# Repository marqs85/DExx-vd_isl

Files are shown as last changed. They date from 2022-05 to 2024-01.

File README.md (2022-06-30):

DExx-vd_isl
==============

DExx-vd_isl is advanced video digitizer add-on module for a number of Terasic FPGA development boards. It has been initially used as a development board for OSSC Pro scan converter but over time has been tailored towards a standalone product. Please check the [wikipage](https://junkerhq.net/xrgb/index.php?title=DExx-vd_isl) for more information on usage and latest features.

[PCB](pcb/) and firmware of the project are open-source except for certain Intel VIP modules which are planned to be replaced by custom implementations over time. For most parts RTL and SW are derived from OSSC Pro [project](https://github.com/marqs85/ossc_pro/) with only small amount of adaptation code for the supported development boards.

Supported Terasic boards and board specific notes
----------------------------------------------------
* [DE10-Nano](board/de10-nano)
* [C5G](board/c5g)
* [DE2-115](board/de2-115)

Requirements for building and debugging firmware
---------------------------------------------------
* Hardware
  * DExx-vd_isl module and compatible development board

* Software
  * [Altera Quartus Prime + device support files for target FPGA family](http://dl.altera.com/?edition=lite) (v 21.1 or higher - free Lite Edition suffices)
  * Make

Building RTL (bitstream)
--------------------------
1. Load the project (board/\<board\>/\<boardname\>.qpf) in Quartus
2. Generate QSYS output files (only needed before first compilation or when QSYS structure has been modified)
    * Open Platform Designer (Tools -> Platform Designer)
    * Load platform configuration (sys.qsys)
    * Generate output (Generate -> Generate HDL, Generate)
    * Close Platform Designer
3. Build software image if not yet done so that it becomes part of the bitstream (see next section)
4. Generate the FPGA bitstream (Processing -> Start Compilation)
5. Ensure that there are no major timing violations by looking into Timing Analyzer report

NOTE: If the software image (software/sys_controller/mem_init/sys_onchip_memory2_0.hex) was not up to date at the time of compilation, bitstream can be quickly rebuilt with updated hex by running "Processing->Update Memory Initialization File" and "Processing->Start->Start Assembler" in Quartus.

NOTE2: Without Intel VIP license it's only possible to generate a time limited bitstream which needs connection to USB Blaster during use. VIP modules can be excluded by commenting out the "VIP" define from both top-level RTL and sysconfig.h in which case scaler mode is disabled.

Building software image
--------------------------
1. Generate software BSP (first-time only)
~~~~
cd board/<board>/software/sys_controller_bsp
nios2-bsp-generate-files --settings=settings.bsp --bsp-dir=.
~~~~
2. Enter software root directory:
~~~~
cd board/<board>/software/sys_controller
~~~~
3. Build SW for target configuration:
~~~~
make [OPTIONS] [TARGET]
~~~~
OPTIONS may include following definitions:
* APP_CFLAGS_DEFINED_SYMBOLS="-DDEBUG" (debug message are printed to stdout connected to JTAG UART, shown via nios2-terminal)

TARGET is typically one of the following:
* all (Default target. Compiles an ELF file)
* mem_init_generate (Generates a memory initialization file required for bitstream)
* clean (cleans ELF and intermediate files. Should be invoked every time OPTIONS are changed between compilations)

4. Optionally test updated SW by directly downloading memory image to block RAM via JTAG (with DE10-Nano TCK needs to be reduced, see board specific notes)
~~~~
nios2-download sys_controller.elf --go
~~~~

Bitstream deployment
----------------------
Depending on target platform, bitstream can be either stored into serial flash chip or SD card where it is automatically loaded every time FPGA is subsequently powered on.

To program flash on compatible boards, FPGA configuration file must be first converted into JTAG indirect Configuration file (.jic). Open conversion tool ("File->Convert Programming Files") in Quartus, click "Open Conversion Setup Data", select "ossc.cof" and press Generate. Then open Programmer, add generated file (output_files/<filename>.jic) and press Start after which flash is programmed. Installed/updated firmware is activated after power-cycling the board.

See board specific notes for building a SD card image containing the bitstream.

Debugging
------------
1. Rebuild the software in debug mode:
~~~~
make clean && make APP_CFLAGS_DEBUG_LEVEL="-DDEBUG" mem_init_generate
~~~~
2. Download memory image via JTAG and open terminal for UART
~~~~
nios2-download sys_controller.elf --go && nios2-terminal
~~~~
Remember to close nios2-terminal after debug session, otherwise any JTAG transactions will hang/fail.

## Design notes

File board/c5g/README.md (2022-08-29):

DExx-vd_isl on C5G
===========================

Hardware notes
-----------------
* C5G has series resistors between GPIO and FPGA (close solder jumper JP1)
* Digital audio needs to be connected directly to respective ADV7513 "test" pads

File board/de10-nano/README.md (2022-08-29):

DExx-vd_isl on DE10-Nano
===========================

Hardware notes
-----------------
* DE10-Nano has no series resistors between GPIO and FPGA (make sure JP1 is open)
* Uses GPIO0 block by default and Arduino header (D[7:4]) closest to FPGA
  * GPIO1 can be used with FW from de10n_gpio1 branch (useful for people using a Mister RAM expansion on GPIO0)
* Uses Nios2 soft-CPU to be in line with other board adaptations
  * TODO: evaluate if hard ARM core could be utilized with minimal configuration/code changes
* DE10-Nano user LEDs are too tightly packed and all same color so they are not much of use
* SPDIF input of ADV7513 is not connected (board can be modified to support SPDIF, see below)
* Due to booting from HPS, EPCQ flash is not accessible. Settings are stored on SD card

SPDIF mod
------------
In order to enable SPDIF support, a small modification needs to be applied on DE10-Nano.

Connect one end of a ~10cm kynar wire to pin 3 of ADV7513 as shown below.
DE10-Nano top SPDIF mod

On bottom side of the PCB, connect other end of the wire to Arduino IO4/D4 pin.
DE10-Nano bottom SPDIF

Building SD card image
-------------------------
See [README-bootloader.txt](README-bootloader.txt)

Debugging notes
------------------
Nios2 JTAG doesn't work with the default TCK frequency of the on-board USB-Blaster. Before SW download, open "Quartus Programmer -> Hardward Setup" and set the frequency to 6.5MHz.

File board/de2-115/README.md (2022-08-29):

DExx-vd_isl on DE2-115
===========================

Hardware notes
-----------------
* DE2-115 has series resistors between GPIO and FPGA (close solder jumper JP1)
* 4-pin audio cable is connected to 14-pin IO connector (EX_IO[3:0])
* The firmware utilizes IR receiver and character display of DE2-115, thus these parts can be omitted from DExx-vd_isl
* Video output is through DE2-115 VGA and custom HDMI HSMC expansion card
* Scaler mode performance is lower compared to other boards due to SDRAM and Cyclone IV limitations

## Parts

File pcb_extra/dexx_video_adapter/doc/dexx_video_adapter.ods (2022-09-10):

Ref | Qnty | Value | MPN | Vendor URL
J1, | 1 | SCART-F | SCART-17 | https://www.tme.eu/en/details/scart-17/euro-hdmi-connectors/ninigi/
J2, | 1 | Pr | RCJ-022 | https://www.digikey.fi/en/products/detail/cui-devices/RCJ-022/408494
J3, | 1 | Y | RCJ-026 | https://www.digikey.fi/en/products/detail/cui-devices/RCJ-026/408498
J4, | 1 | Pb | RCJ-025 | https://www.digikey.fi/en/products/detail/cui-devices/RCJ-025/408497
J5, | 1 | AudioJack3 | SJ1-3533NG | https://www.digikey.fi/en/products/detail/cui-devices/SJ1-3533NG/738701
J6, | 1 | DB15_Female_HighDensity | ICD15S13E4GV00LF | https://www.digikey.fi/en/products/detail/amphenol-cs-fci/ICD15S13E4GV00LF/1536418

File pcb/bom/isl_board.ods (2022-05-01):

Type | Id | Designator | Package | Quantity | Designation | MPN | Alternative part | Supplier URL
ICs
 | 30 | U5 | MQFP-128_thermal | 1 | ISL51002 | ISL51002CQZ-110 | ISL51002CQZ-165 | https://www.digikey.fi/en/products/detail/intersil/ISL51002CQZ-110/11516216
 | 31 | U6 | QFN-20-1EP_4x4mm_Pitch0.5mm_Handsoldering | 1 | Si5351C | SI5351C-B-GM |  | https://www.mouser.fi/ProductDetail/Silicon-Labs/SI5351C-B-GM/
 | 32 | U7 | PCM1808PWR | 1 | PCM1808PWR | PCM1808PWR |  | https://www.mouser.fi/ProductDetail/Texas-Instruments/PCM1808PWR
Regulators
 | 27 | U1 | SOT-23-5_Handsoldering | 1 | LM3671MF-2.5/NOPB | LM3671MF-2.5/NOPB |  | https://www.mouser.fi/ProductDetail/Texas-Instruments/LM3671MF-25-NOPB?qs=QbsRYf82W3EGm7MxEdl1Ew%3D%3D
 | 28 | U2 | SOT-23-5_Handsoldering | 1 | TLV70033DDC | TLV70033DDCR |  | https://www.mouser.fi/ProductDetail/595-TLV70033DDCR
 | 29 | U3,U4 | SOT-23-5_Handsoldering | 2 | TLV75518P | TLV75518PDBVR |  | https://www.mouser.fi/ProductDetail/Texas-Instruments/TLV75518PDBVR?qs=55YtniHzbhCKl5yPgBW9OQ%3D%3D
Connectors / switch
 | 11 | J1 | Pin_Header_Straight_2x20_Pitch2.54mm | 1 | CONN_02X20 | SFH11-PBPC-D20-ST-BK | 8540-4500PL | https://www.digikey.com/en/products/detail/sullins-connector-solutions/SFH11-PBPC-D20-ST-BK/1990093
 | 12 | J2,J5 | PinHeader_2x04_P2.54mm_Vertical | 2 | CONN_02X04 | 10129381-908002BLF |  | https://www.mouser.fi/ProductDetail/Amphenol-FCI/10129381-908002BLF
 | 14 | J4 | SCART_CONN | 1 | SCART-F | K-SCARTX-022 | CS-107
 | 33 | U8 | Vishay_CAST-3Pin | 1 | TSOP31338 | TSOP31338 |  | https://www.mouser.fi/ProductDetail/Vishay-Semiconductors/TSOP31338
 | 10 | DS1 | PinHeader_1x20_P2.54mm_Vertical | 1 | NHD-0216CW-AW3 | 68001-420HLF |  | https://www.mouser.fi/ProductDetail/Amphenol-FCI/68001-420HLF
 | 26 | SW1 | PinHeader_1x03_P2.54mm_Vertical | 1 | SW_SPDT | MSS-102559-14A-D | 450301014042 | https://www.mouser.fi/ProductDetail/CUI-Devices/MSS-102559-14A-D?qs=DRkmTr78QAQJ9kylFXtWnw%3D%3D
Misc
 | 13 | J3 | FCR684208R | 1 | FCR684208R | FCR684208R |  | https://www.digikey.fi/en/products/detail/cliff-electronic-components-ltd/FCR684208R/15283092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
 | 34 | Y1 | ECS-3X9X | 1 | 27MHz | ECS-270-18-9X |  | https://www.mouser.fi/ProductDetail/ECS/ECS-270-18-9X
SMD R/L/C
 | 1 | C24,C25 | SM0603_Capa_libcms | 2 | 22p | CC0603JRNPO9BN220 |  | https://www.mouser.fi/ProductDetail/YAGEO/CC0603JRNPO9BN220?qs=vTakOoo5QyIVMYOUTI%2F4zA%3D%3D
 | 2 | C27,C30 | SM0603_Capa_libcms | 2 | 50p | CC0603JRNPO9BN500 |  | https://www.mouser.fi/ProductDetail/YAGEO/CC0603JRNPO9BN500?qs=UgE%2F0m3bTsZTB58yeBnmuQ%3D%3D
 | 3 | C48,C47,C13,C22,C23 | SM0603_Capa_libcms | 5 | 1n | CC0603JRX7R9BB102 |  | https://www.mouser.fi/ProductDetail/YAGEO/CC0603JRX7R9BB102?qs=AgBp2OyFlx9XcQsP2DKqzg%3D%3D
 | 4 | C20 | SM0603_Capa_libcms | 1 | 10n | CC0603JRX7R9BB103 |  | https://www.mouser.fi/ProductDetail/YAGEO/CC0603JRX7R9BB103?qs=AgBp2OyFlx9BIx0qrdQtpQ%3D%3D
 | 5 | C53,C39,C52,C42,C44,C43,C51,C9,C10,C11,C12,C14,C15,C16,C17,C18,C19,C21,C26,C28,C29,C31,C32,C33,C34,C35,C36,C37,C38,C41 | SM0603_Capa_libcms | 30 | 0.1u | CC0603JRX7R9BB104 |  | https://www.mouser.fi/ProductDetail/YAGEO/CC0603JRX7R9BB104?qs=57cj7OiSijmjSM%252BQadQODQ%3D%3D
 | 6 | C1,C2,C3,C6,C7,C8 | SM0603_Capa_libcms | 6 | 1u | CC0603KRX7R8BB105 |  | https://www.mouser.fi/ProductDetail/YAGEO/CC0603KRX7R8BB105?qs=57cj7OiSijm1JqG%252BGXtOuQ%3D%3D
 | 7 | C50,C49 | SM0805_libcms | 2 | 1u | CC0805KRX5R6BB105 | TPSR105K020R6000 | https://www.mouser.fi/ProductDetail/YAGEO/CC0805KRX5R6BB105?qs=57cj7OiSijlFWI8EUNwoXQ%3D%3D
 | 8 | C4,C5 | SM0603_Capa_libcms | 2 | 10u | CC0603MRX5R5BB106 |  | https://www.mouser.fi/ProductDetail/YAGEO/CC0603MRX5R5BB106?qs=hvk6vzacGVh2hHrHyirv6Q%3D%3D
 | 9 | C45,C46 | SM0805_libcms | 2 | 10u | CC0805KRX5R6BB106 | TCTOP1A106M8R | https://www.mouser.fi/ProductDetail/YAGEO/CC0805KRX5R6BB106?qs=57cj7OiSijmmkjVzLrgcdg%3D%3D
 | 15 | L1 | SM0603_Capa_libcms | 1 | 2.2u | CDRH2D14NP-2R2NC |  | https://www.mouser.fi/ProductDetail/Sumida/CDRH2D14NP-2R2NC
 | 16 | R25,R21,R23,R34,R27,R31,R22,R32,R33,R24,R28,R26,R2,R4,R5,R6,R7,R11,R12,R15,R16,R17,R18,R19,R20,R29,R30,R35,R36 | SM0603_Resistor_libcms | 29 | 22 | RC0603FR-0722RL |  | https://www.mouser.fi/ProductDetail/YAGEO/RC0603FR-0722RL?qs=diQw95jMAeMOsxb8bne7fg%3D%3D
 | 17 | R10,R48 | SM0603_Resistor_libcms | 2 | 50 | RC0603FR-0749R9L |  | https://www.mouser.fi/ProductDetail/YAGEO/RC0603FR-0749R9L?qs=NEN%2FsE%2FLsvNRW8WFDtCPgQ%3D%3D
 | 18 | R41,R42,R43,R44 | SM0603_Resistor_libcms | 4 | 75 | RT0603DRE0775RL |  | https://www.mouser.fi/ProductDetail/YAGEO/RT0603DRE0775RL?qs=4CyHz7GXqShxnJgXynoRqg%3D%3D
 | 19 | R1 | SM0603_Resistor_libcms | 1 | 500 | RC0603FR-07499RL |  | https://www.mouser.fi/ProductDetail/Yageo/RC0603FR-07499RL/
 | 20 | R8,R13,R51 | SM0603_Resistor_libcms | 3 | 1k | RC0603FR-071KL |  | https://www.mouser.fi/ProductDetail/Yageo/RC0603FR-071KL/
 | 21 | R9,R14 | SM0603_Resistor_libcms | 2 | 1.9k | RC0603FR-071K91L |  | https://www.mouser.fi/ProductDetail/YAGEO/RC0603FR-071K91L?qs=ZACZTsJ%2FqZhXlEC9cKEQ2Q%3D%3D
 | 22 | R3,R37,R39,R40 | SM0603_Resistor_libcms | 4 | 2.2k | RC0603FR-072K2L |  | https://www.mouser.fi/ProductDetail/YAGEO/RC0603FR-072K2L?qs=diQw95jMAeOQmNpe2MM%252BPw%3D%3D
 | 23 | R46,R47 | SM0603_Resistor_libcms | 2 | 3.3k | RC0603FR-073K3L |  | https://www.mouser.fi/ProductDetail/YAGEO/RC0603FR-073K3L?qs=gt6vzsuosg2EoNiKbtAsfQ%3D%3D
 | 24 | R38,R45 | SM0603_Resistor_libcms | 2 | 4.7k | RC0603FR-074K7L |  | https://www.mouser.fi/ProductDetail/YAGEO/RC0603FR-074K7L?qs=gt6vzsuosg37y0l7Vt36bQ%3D%3D
 | 25 | R50,R49 | SM0603_Resistor_libcms | 2 | 10k | RC0603FR-0710KL |  | https://www.mouser.fi/ProductDetail/YAGEO/RC0603FR-0710KL?qs=grNVn54RoB%252B3GtjbJj3wJQ%3D%3D
Display assembly (optional)
 |  | DS1-DISP |  | 1 |  | NHD-0216CW-AW3 | NHD-0216CW-AG3 | https://www.mouser.fi/ProductDetail/Newhaven-Display/NHD-0216CW-AW3
 |  | DS1-CONN |  | 1 |  | PPTC201LGBN-RC | 801-83-020-20-001101 | https://www.digikey.com/en/products/detail/sullins-connector-solutions/PPTC201LGBN-RC/775914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
Audio cable

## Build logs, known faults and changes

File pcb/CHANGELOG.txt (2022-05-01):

v1.0 (09/2017)

* initial version

v1.1 (12/2018)

* route clocks to GPIO instead of SMA
* add audio support (ADC + SPDIF input)
* add new signals to ISL pin header

v1.2 (02/2020)

* change XTAL to 24.576MHz and route buffered output directly to audio ADC
* add optional support for IR receiver and character display
* add Si5351C Xin voltage divider
* fix SCART mount hole
* fix SPDIF connector pin connections

v1.3 (08/2020)

* change IR receiver position
* change PCB to 4-layer
* swap pclk to different gpio to minimize crosstalk
* revert v1.2 XTAL change
* update regulators and power routing
* csync/sog switch added

v1.4 (04/2022)

* revert pclk gpio change
* connect pclk directly to clkgen
* optimize BOM

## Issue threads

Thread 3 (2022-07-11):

Request: FW .58 Release

atrac17, 2022-07-11:
Could you please provide a release for the newest FW with profile saving/loading? I setup up a build env to compile the software image, but it is pointless as I do not have the Intel VIP license.

Also, have you considered adding support for the custom_scaler profiles that can be loaded via .txt? I'd like to try the **[scaler methods](https://github.com/atrac17/Integer_Video_Modes)** I use on MiSTer with this device. If not, profiles will suffice. Thank you for this wonderful project.

atrac17, 2022-07-11:
I'd like to use my own ini files with custom video modes for HW on the scaler side. Assume this is where "custom _scaler.txt" comes into play.

marqs85, 2022-07-11:
Sampling presets can be customized and are saved as part of a profile. It's also planned that the output mode parameters (ref. video_modes[]) could be tweaked as they are also included in the profile. A profile import/export feature (i.e. from/to SD card) is a planned feature since it's supported already by OSSC Classic. That should allow definition of custom table of video modes.

With DExx / OSSC Pro the profile could be encoded/decoded to/from txt format opposed to binary data on Classic which needs some work on a parser etc.

atrac17, 2022-07-11:
I assume the load/save profile for the DExx is not limited? It's probably best to go this route for arcade hardware. I have about 60 PCB's that I would like to make custom profiles.

I do "hybrid scaling", it's compatible with the OSSC "classic". The pre-defined Neo Geo mode on the DExx FW would be an example.

If a .txt file could be parsed, how would parameters be defined? I have several listed  **[here](https://github.com/atrac17/Integer_Video_Modes)**.

marqs85, 2022-07-12:
It seems the on-board flash can be only accessed if the FPGA boots from it (AS mode) which is an annoying Cyclone V limitation. I'll have to next try if loaning SD pins to FPGA side works so that profiles could be saved there while retaining HPS-based boot. SD cards should at least have space for practically infinite amount of profiles.

Regarding parsing, you can see the struct members for a sampling preset [here](https://github.com/marqs85/ossc_pro/blob/2275b124a579b4f84cc87528a749310c679546f6/software/sys_controller/inc/video_modes.h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).

marqs85, 2022-07-23:
25f425dc7346ee215d746c51cfede3ab62e99db0 now implements a framework for saving & loading profiles (up to 100) on SD. However, there is one remaining issue in SD card controller with regards to write which needs to be resolved before the firmware can be released.

atrac17, 2022-07-23:
Great work, thank you!

marqs85, 2022-07-25:
There is now a beta [image](http://www.infocult.com/m/tmp/sdcard_cv_058beta2.img.zip) which supports storing profiles on SD. 2 MiSTer filters can be also put on the card as scaler1.txt and scaler2.txt and activated from Scaling Algorithm menu.

atrac17, 2022-07-25:
Awesome, I'll give it a go here shortly. Thank you very much.

jaffa225, 2022-07-26:
> There is now a beta [image](http://www.infocult.com/m/tmp/sdcard_cv_058beta2.img.zip) which supports storing profiles on SD. 2 MiSTer filters can be also put on the card as scaler1.txt and scaler2.txt and activated from Scaling Algorithm menu.

My settings are saving and reloading properly (Thanks!), but I didn't test the MISTer filters options yet.  This is a real time-saver for me, and very appreciated! :)

atrac17, 2022-07-29:
Thanks again @marqs85! Closing this.

marqs85, 2022-07-29:
The SD card issues should be now properly fixed in c4d6a4a.

jaffa225, 2022-08-02:
> The SD card issues should be now properly fixed in [c4d6a4a](https://github.com/marqs85/DExx-vd_isl/commit/c4d6a4af24cbbef8543f654cacb34da9c032a3d4).

I hadn't noticed any issue with it, but thank you!  I know what it's like to notice when my own patches need improvement.  I'm happily up-to-date now, and even my previously saved profile & settings were easily copied back to restore on firmware version 0.59.

Closed 2022-07-29.

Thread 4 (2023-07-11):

[Request] Update to latest OSSC Pro changes

MP2E, 2023-07-11:
Hi there, thank you for your work on the OSSC standard and Pro! I use the DExx-vd_isl with my Sharp X68000 and I noticed there are some fixes and new profiles for it in the latest OSSC Pro release. Could we please see those changes ported over here? Would love to try them out.

Thanks again

marqs85, 2023-07-11:
That's a good point, it hasn't been updated in a while. I can integrate the changes and generate a new version later this week.

Regarding X68k, the one machine I've tested required sync combiner circuit for a stable picture for yet unknown reason. I didn't see anything strange on the usual H+V sync via scope. Not sure if that applies to your setup.

marqs85, 2023-07-13:
Version 0.66 is now available with the latest changes integrated.

MP2E, 2023-07-13:
Thank you very much! I appreciate it

MP2E, 2023-07-13:
Just tested it out with my X68K and everything is working wonderfully! Now 24khz mode works, which wasn’t the case before

thanks again!!

marqs85, 2023-07-13:
Out of curiosity, which kind of adapter you use to hook X68k to DExx's SCART input?

MP2E, 2023-07-13:
I’m using this adapter: https://castlemaniagames.com/products/rondo-products-hd15-2-scart

with a standard VGA video cable and this adapter to hook up to the X68K

https://www.ebay.com/itm/235004706792

Closed 2023-07-13.

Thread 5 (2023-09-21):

15KHz 240p widescreen output and unable to load profile via remote preset

MarcoRetro, 2023-09-21:
Great product. I’m wondering if there’ll be a 240p 15KHz WS mode, as currently 16:9 content is further squished. Also, is there a way to load profiles with the remote? The bottom left profile button doesn’t seem to do anything

marqs85, 2023-09-23:
So basically you'd like to have a "240p WS" scaler CRT output preset? It's certainly trivial to add even though I can't think of much 16:9 content that I'd run at 240p. Handler for profile load button is not yet implemented but it's not much work and could be included in next firmware as well.

MarcoRetro, 2023-09-23:
Yes correct, 240p WS. It’s a niche user-case but for the few of us downscaling to a widescreen 15KHz CRT. Thanks Marqs!

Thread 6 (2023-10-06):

480p RGBHV Downscaling unstable

MarcoRetro, 2023-10-06:
When there is an RGBHV 480p input to 240p output in line-multiplier or scaler mode, the screen frequently 'jumps'

marqs85, 2023-10-07:
Have you tried applying the modification detailed [here](https://videogameperfection.com/forums/topic/dexx-vd_isl-horizontal-jitter-in-scaling-mode/)?

MarcoRetro, 2023-10-07:
I haven’t tried that. I have GPIO1 configuration, does the Dexx still need to be removed when the DE-10 is not booting the Dexx FW with the solder-blob fix?

marqs85, 2023-10-23:
It's highly recommended since the blob connects one GPIO pin (potentially output with some other application running on DE10-Nano) to GND.

MarcoRetro, 2023-10-24:
Thanks kindly for the reply! So I tried the fix by grounding the GPIO pin on the Dexx board but a 480p input downscaled to 15KHz still jumps, in scaler and line multiplier output

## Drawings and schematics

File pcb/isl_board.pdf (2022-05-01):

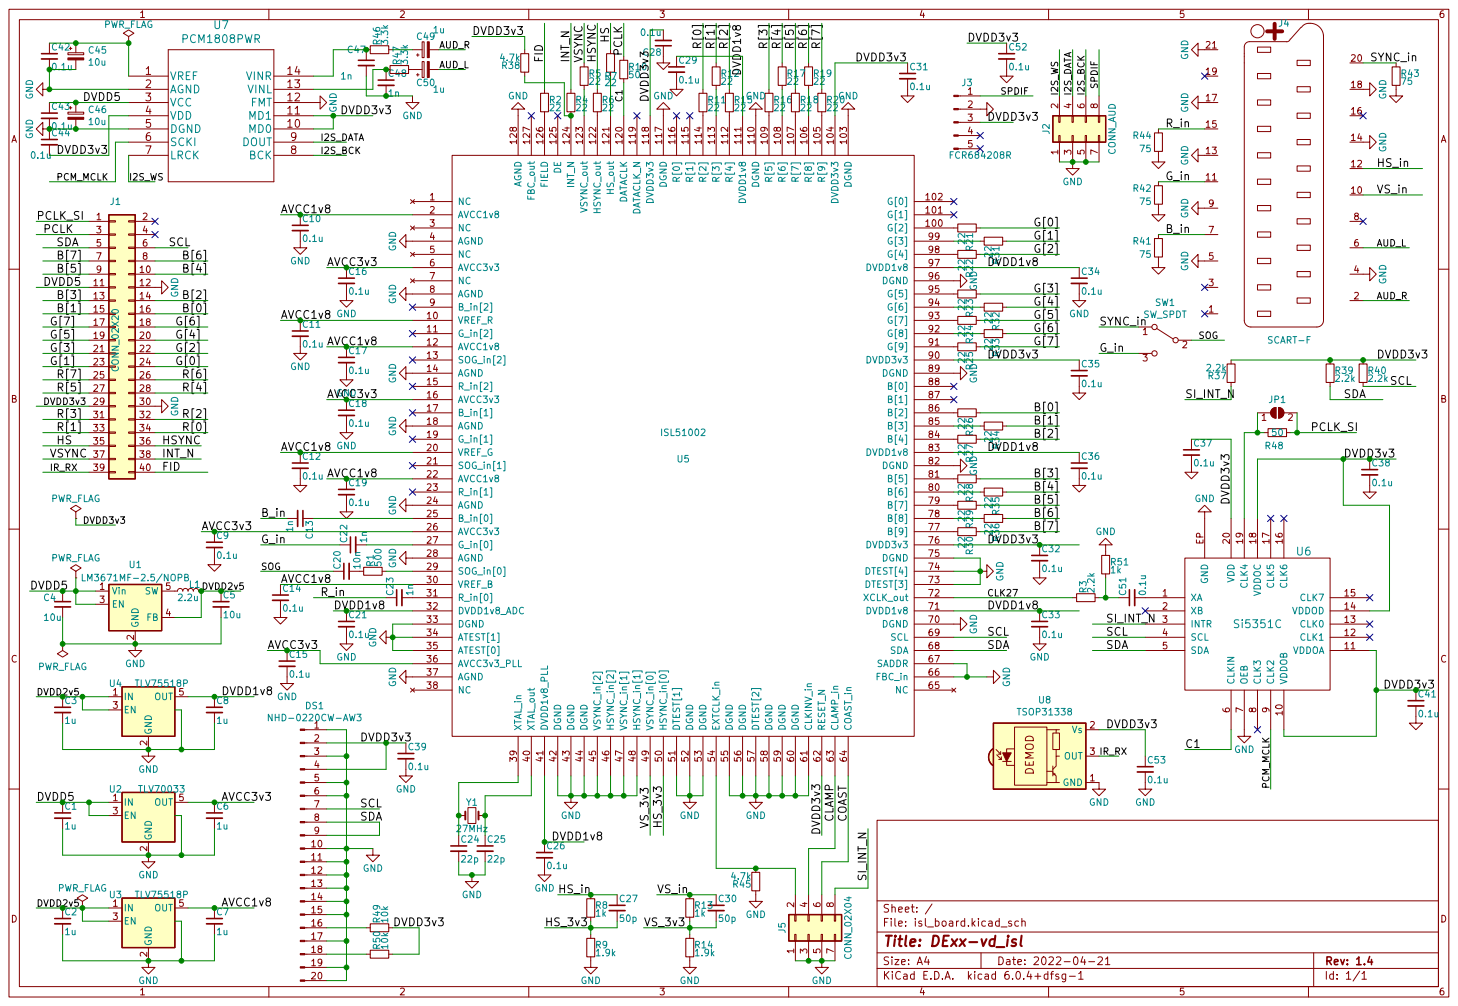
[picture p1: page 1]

2 EN 3 OUT 5 U3 TLV75518P GND GND

B[0]
G[6]

20 G[4]
G[2]

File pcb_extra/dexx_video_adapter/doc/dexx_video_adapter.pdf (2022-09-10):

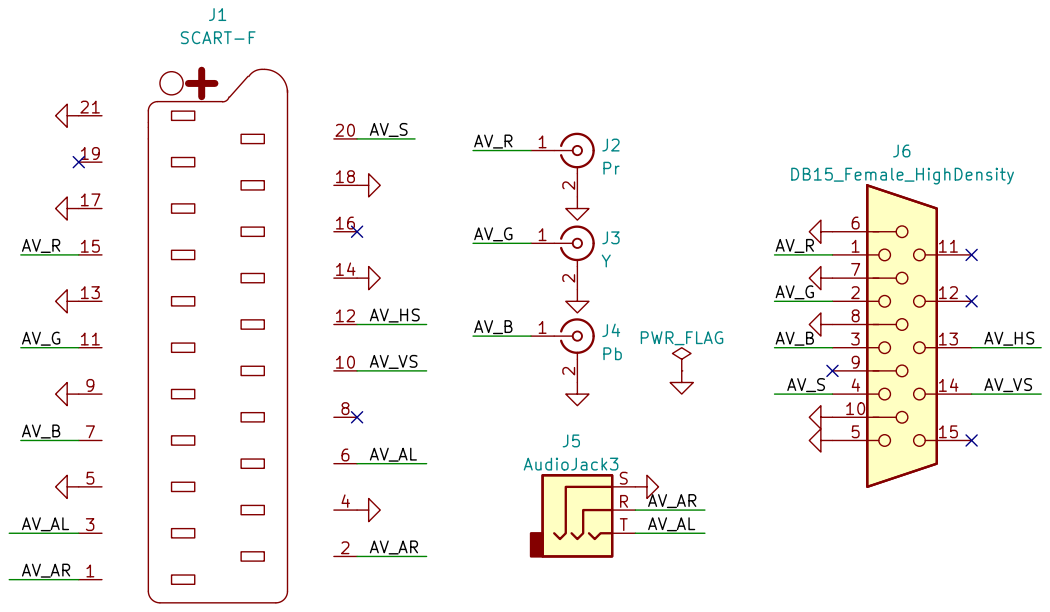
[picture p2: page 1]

File: dexx_video_adapter.kicad_sch Sheet: /
Id: 1/1 Title: DExx AV adapter

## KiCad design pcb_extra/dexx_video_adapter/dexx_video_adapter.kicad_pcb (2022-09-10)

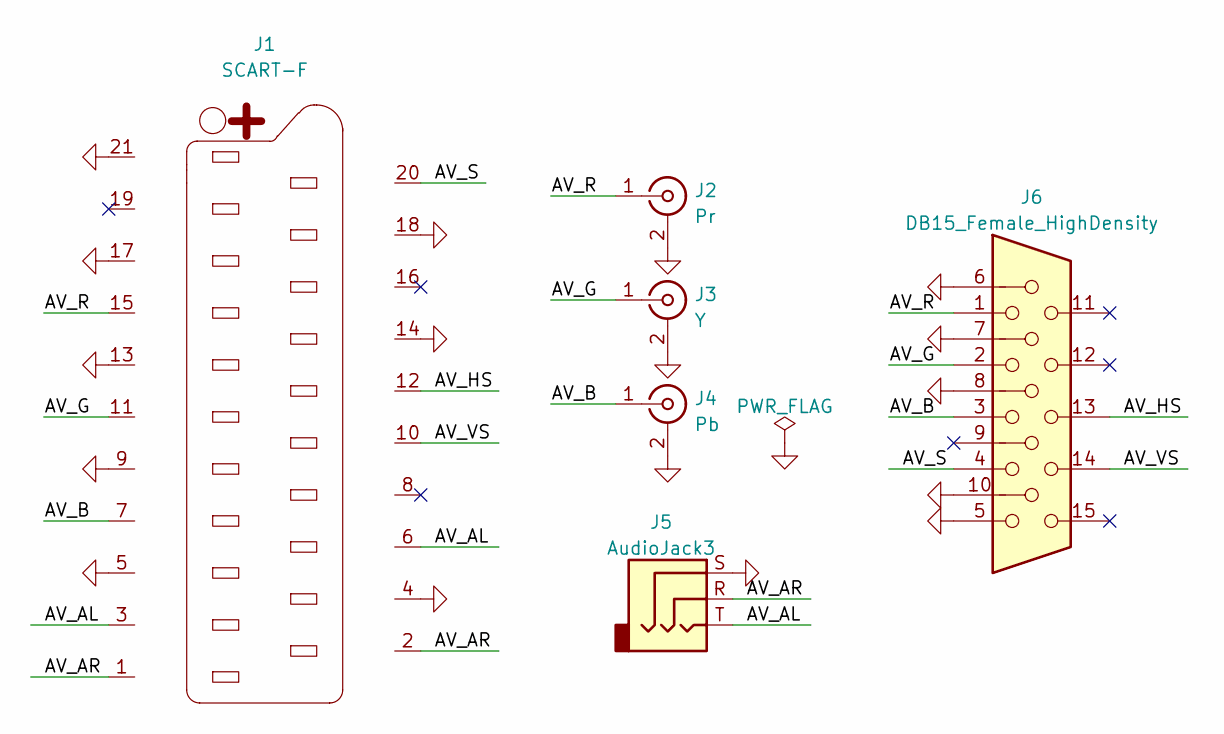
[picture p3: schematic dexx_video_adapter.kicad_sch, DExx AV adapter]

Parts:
J1: SCART-F; SCART_CONN
J2: Pr; CUI_RCJ-022
J3: Y; CUI_RCJ-022
J4: Pb; CUI_RCJ-022
J5: AudioJack3; SJ1-3533NG
J6: DB15_Female_HighDensity; VGA_CONN

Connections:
/AV_AL: J1.3, J1.6, J5.T
/AV_AR: J1.1, J1.2, J5.R
/AV_B: J1.7, J4.1 (In), J6.3
/AV_G: J1.11, J3.1 (In), J6.2
/AV_HS: J1.12, J6.13
/AV_R: J1.15, J2.1 (In), J6.1
/AV_S: J1.20, J6.4
/AV_VS: J1.10, J6.14
GND: J1.4, J1.5, J1.9, J1.13, J1.14, J1.17, J1.18, J1.21, J2.2 (Ext), J3.2 (Ext), J4.2 (Ext), J5.S, J6.5, J6.6, J6.7, J6.8, J6.10

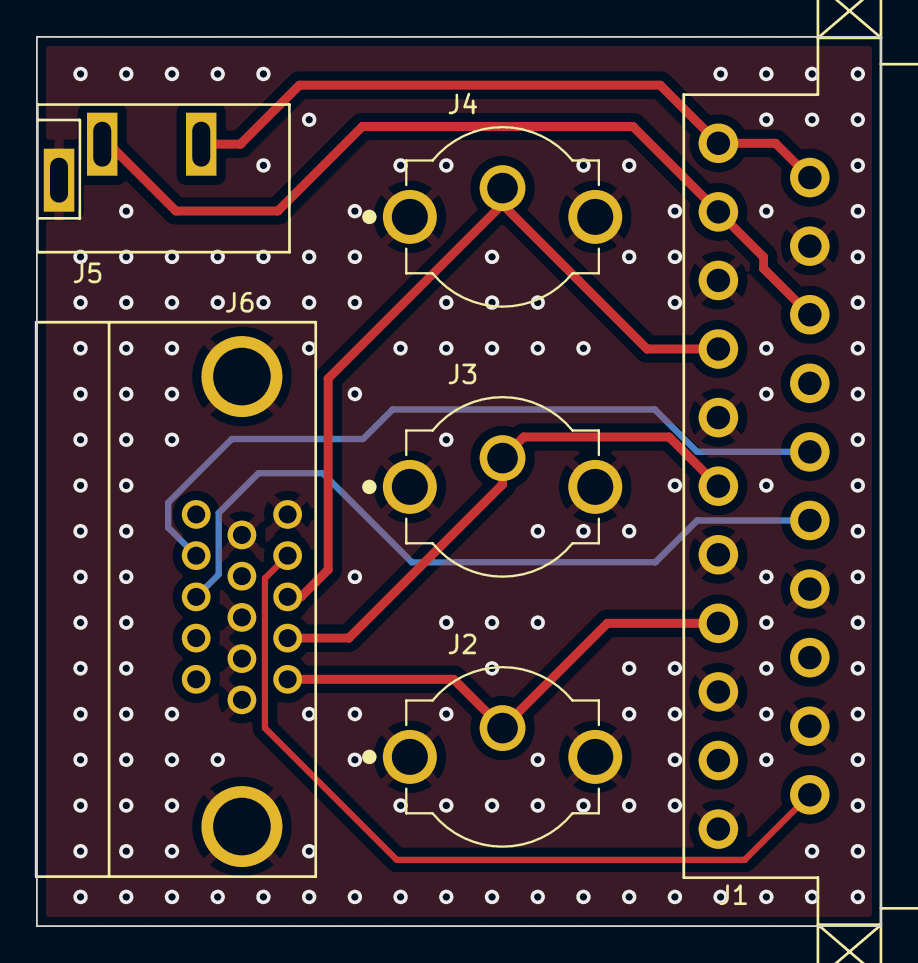
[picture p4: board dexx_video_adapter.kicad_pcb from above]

Board: 2 copper layers, 46.9 x 49.4 mm, 6 parts (0 on the bottom side), 9 nets.

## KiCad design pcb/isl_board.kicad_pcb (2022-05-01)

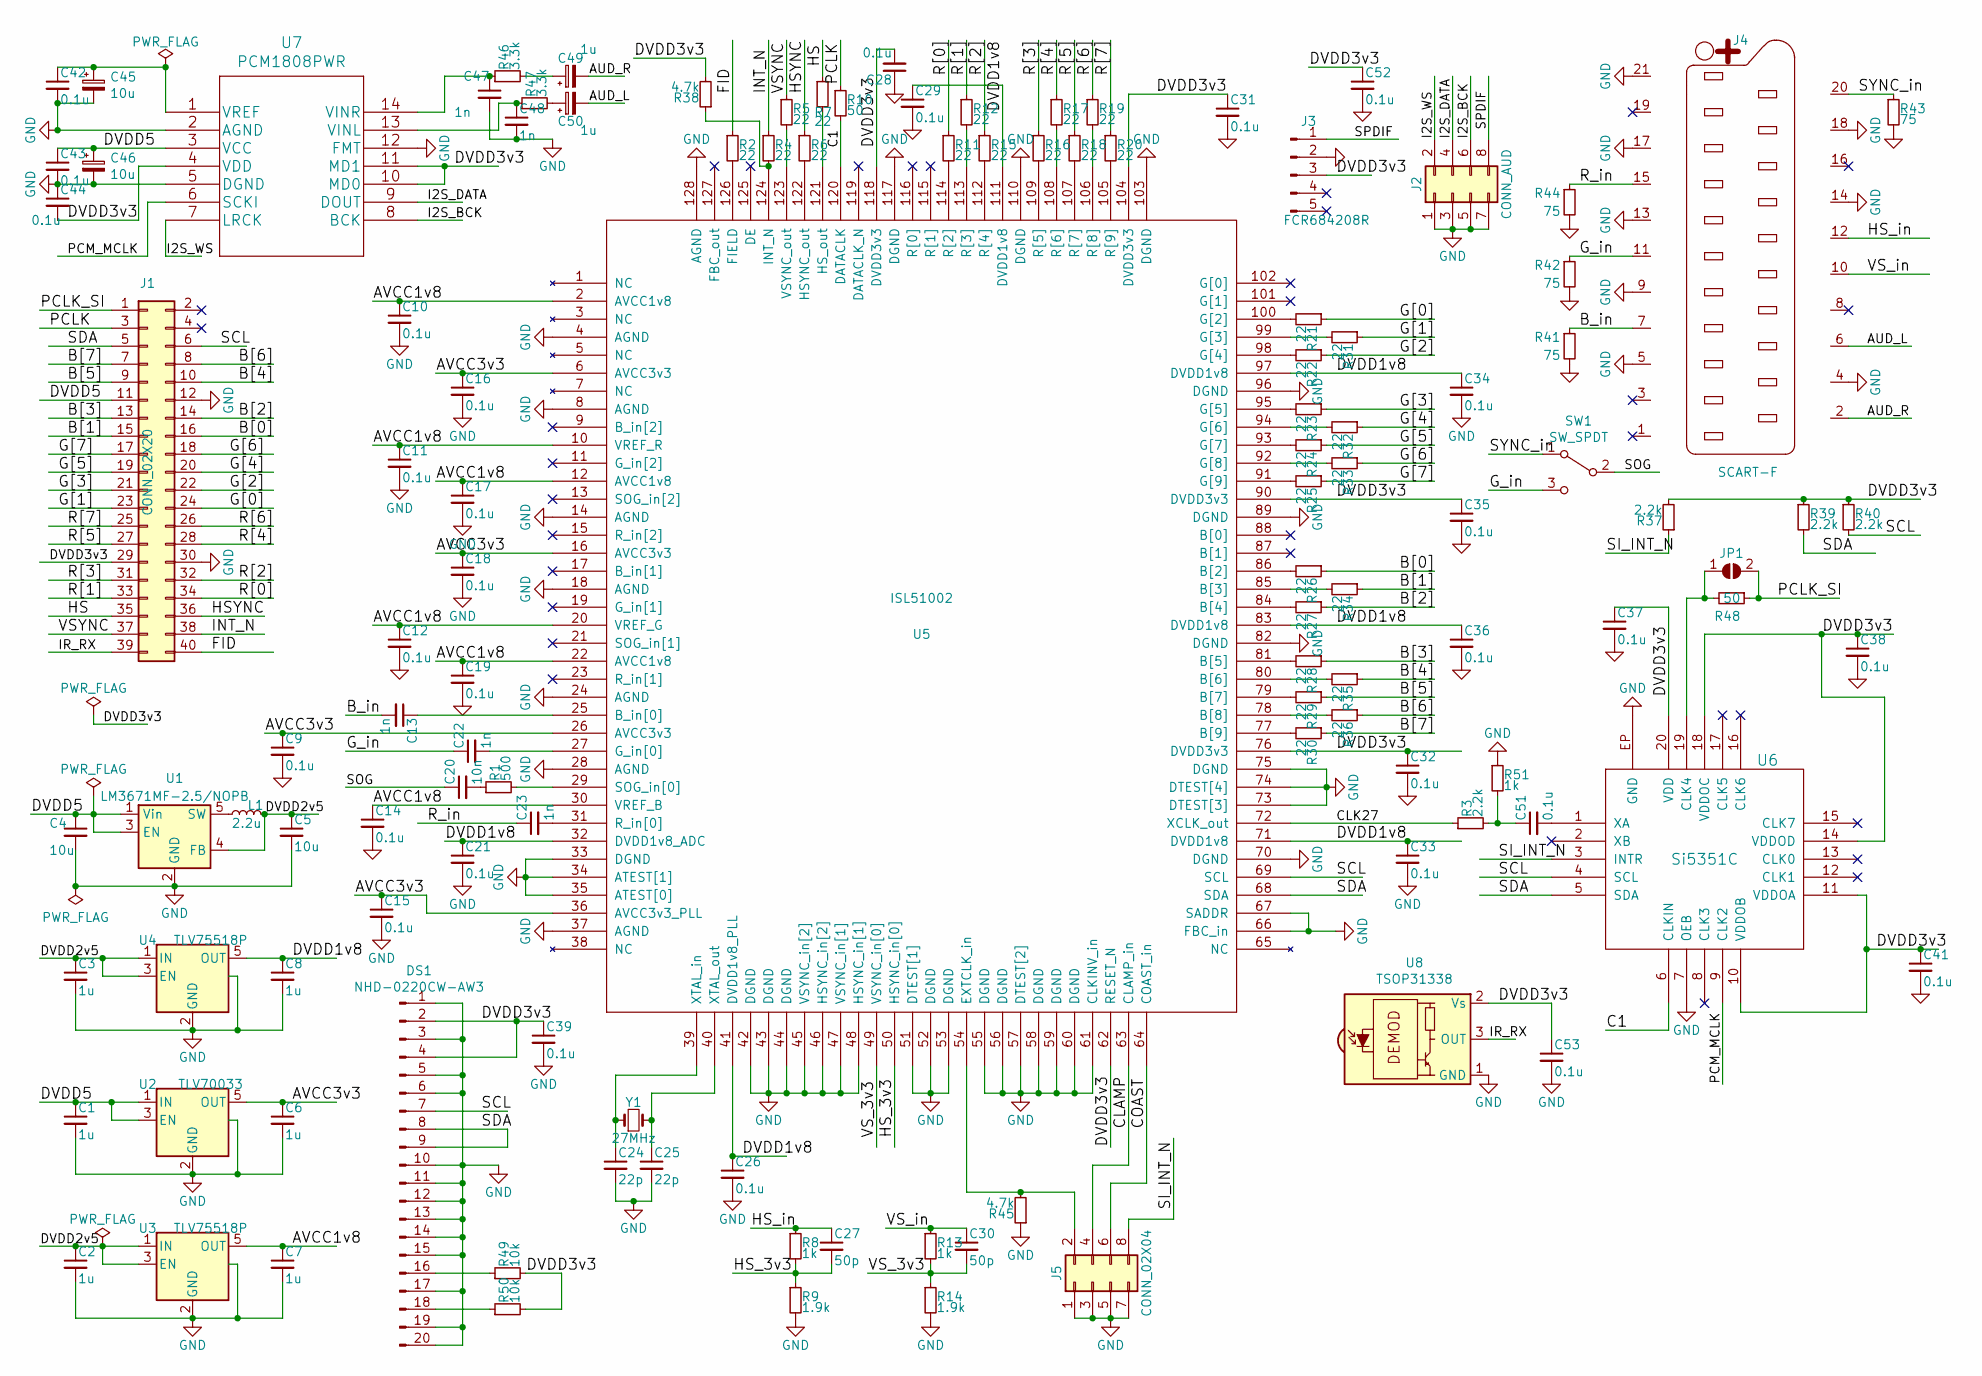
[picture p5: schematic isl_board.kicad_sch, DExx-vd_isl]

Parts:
C1, C2, C3, C6, C7, C8: 1u; SM0603_Capa_libcms
C4, C5: 10u; SM0603_Capa_libcms
C9, C10, C11, C12, C14, C15, C16, C17, C18, C19, C21, C26, C28, C29, C31, C32, C33, C34, C35, C36, C37, C38, C39, C41, C42, C43, C44, C51, C52, C53: 0.1u; SM0603_Capa_libcms
C13, C22, C23, C47, C48: 1n; SM0603_Capa_libcms
C20: 10n; SM0603_Capa_libcms
C24, C25: 22p; SM0603_Capa_libcms
C27, C30: 50p; SM0603_Capa_libcms
C45, C46: 10u; SM0805_libcms
C49, C50: 1u; SM0805_libcms
DS1: NHD-0220CW-AW3; PinHeader_1x20_P2.54mm_Vertical
J1: CONN_02X20; Pin_Header_Straight_2x20_Pitch2.54mm
J2: CONN_AUD; PinHeader_2x04_P2.54mm_Vertical
J3: FCR684208R
J4: SCART-F; SCART_CONN
J5: CONN_02X04; PinHeader_2x04_P2.54mm_Vertical
JP1: SolderJumper_2_Open; SolderJumper-2_P1.3mm_Open_Pad1.0x0.75mm
L1: 2.2u; CDRH2D14
R1: 500; SM0603_Resistor_libcms
R2, R4, R5, R6, R7, R11, R12, R15, R16, R17, R18, R19, R20, R21, R22, R23, R24, R25, R26, R27, R28, R29, R30, R31, R32, R33, R34, R35, R36: 22; SM0603_Resistor_libcms
R3, R37, R39, R40: 2.2k; SM0603_Resistor_libcms
R8, R13, R51: 1k; SM0603_Resistor_libcms
R9, R14: 1.9k; SM0603_Resistor_libcms
R10, R48: 50; SM0603_Resistor_libcms
R38, R45: 4.7k; SM0603_Resistor_libcms
R41, R42, R43, R44: 75; SM0603_Resistor_libcms
R46, R47: 3.3k; SM0603_Resistor_libcms
R49, R50: 10k; SM0603_Resistor_libcms
SW1: SW_SPDT; PinHeader_1x03_P2.54mm_Vertical
U1: LM3671MF-2.5/NOPB; SOT-23-5_Handsoldering
U2: TLV70033; SOT-23-5_Handsoldering
U3, U4: TLV75518P; SOT-23-5_Handsoldering
U5: ISL51002; MQFP-128_thermal
U6: Si5351C; QFN-20-1EP_4x4mm_Pitch0.5mm_Handsoldering
U7: PCM1808PWR
U8: TSOP31338; Vishay_CAST-3Pin
Y1: 27MHz; ECS-3X9X

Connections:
/AUD_L: C50.2, J4.6
/AUD_R: C49.2, J4.2
/AVCC1v8: C7.1, C10.1, C11.1, C12.1, C14.1, C17.1, C19.1, U3.5 (OUT), U5.2 (AVCC1v8), U5.10 (VREF_R), U5.12 (AVCC1v8), U5.20 (VREF_G), U5.22 (AVCC1v8), U5.30 (VREF_B)
/AVCC3v3: C6.1, C9.1, C15.1, C16.1, C18.1, U2.5 (OUT), U5.6 (AVCC3v3), U5.16 (AVCC3v3), U5.26 (AVCC3v3), U5.36 (AVCC3v3_PLL)
/B[0]: J1.16, R26.1
/B[1]: J1.15, R34.1
/B[2]: J1.14, R27.1
/B[3]: J1.13, R28.1
/B[4]: J1.10, R35.1
/B[5]: J1.9, R29.1
/B[6]: J1.8, R36.1
/B[7]: J1.7, R30.1
/B_in: C13.2, J4.7, R41.1
/C1: R10.2, U5.120 (DATACLK), U6.6 (CLKIN)
/CLAMP: J5.4, U5.63 (CLAMP_in)
/CLK27: R3.1, U5.72 (XCLK_out)
/COAST: J5.6, U5.64 (COAST_in)
/DVDD1v8: C8.1, C21.1, C26.1, C29.1, C33.1, C34.1, C36.1, U4.5 (OUT), U5.32 (DVDD1v8_ADC), U5.41 (DVDD1v8_PLL), U5.71 (DVDD1v8), U5.83 (DVDD1v8), U5.97 (DVDD1v8), U5.111 (DVDD1v8)
/DVDD2v5: C2.1, C3.1, C5.1, L1.2, U1.4 (FB), U3.1 (IN), U3.3 (EN), U4.1 (IN), U4.3 (EN)
/DVDD3v3: C28.2, C31.1, C32.1, C35.1, C37.1, C38.1, C39.1, C41.1, C44.2, C52.1, C53.1, DS1.2, DS1.4, J1.29, J3.3, R37.2, R38.2, R39.1, R40.1, R49.2, R50.2, U5.62 (RESET_N), U5.76 (DVDD3v3), U5.90 (DVDD3v3), U5.104 (DVDD3v3), U5.118 (DVDD3v3), U6.10 (VDDOB), U6.11 (VDDOA), U6.14 (VDDOD), U6.18 (VDDOC), U6.20 (VDD), U7.4 (VDD), U7.10 (MD0), U7.11 (MD1), U8.2 (Vs)
/DVDD5: C1.1, C4.1, C43.1, C46.1, J1.11, U1.1 (Vin), U1.3 (EN), U2.1 (IN), U2.3 (EN), U7.3 (VCC)
/FID: J1.40, R2.1
/G[0]: J1.24, R21.1
/G[1]: J1.23, R31.1
/G[2]: J1.22, R22.1
/G[3]: J1.21, R23.1
/G[4]: J1.20, R32.1
/G[5]: J1.19, R24.1
/G[6]: J1.18, R33.1
/G[7]: J1.17, R25.1
/G_in: C22.1, J4.11, R42.1, SW1.3 (C)
/HS: J1.35, R7.1
/HSYNC: J1.36, R6.1
/HS_3v3: C27.2, R8.2, R9.1, U5.50 (HSYNC_in[0])
/HS_in: C27.1, J4.12, R8.1
/I2S_BCK: J2.6, U7.8 (BCK)
/I2S_DATA: J2.4, U7.9 (DOUT)
/I2S_WS: J2.2, U7.7 (LRCK)
/INT_N: J1.38, R4.1
/IR_RX: J1.39, U8.3 (OUT)
/PCLK: J1.3, R10.1
/PCLK_SI: J1.1, JP1.2 (B), R48.1
/PCM_MCLK: U6.9 (CLK2), U7.6 (SCKI)
/R[0]: J1.34, R11.1
/R[1]: J1.33, R12.1
/R[2]: J1.32, R15.1
/R[3]: J1.31, R16.1
/R[4]: J1.28, R17.1
/R[5]: J1.27, R18.1
/R[6]: J1.26, R19.1
/R[7]: J1.25, R20.1
/R_in: C23.1, J4.15, R44.1
/SCL: DS1.7, J1.6, R40.2, U5.69 (SCL), U6.4 (SCL)
/SDA: DS1.8, DS1.9, J1.5, R39.2, U5.68 (SDA), U6.5 (SDA)
/SI_INT_N: J5.8, R37.1, U6.3 (INTR)
/SOG: C20.1, SW1.2 (B)
/SPDIF: J2.8, J3.1
/SYNC_in: J4.20, R43.1, SW1.1 (A)
/VSYNC: J1.37, R5.1
/VS_3v3: C30.2, R13.2, R14.1, U5.49 (VSYNC_in[0])
/VS_in: C30.1, J4.10, R13.1
GND: C1.2, C2.2, C3.2, C4.2, C5.2, C6.2, C7.2, C8.2, C9.2, C10.2, C11.2, C12.2, C14.2, C15.2, C16.2, C17.2, C18.2, C19.2, C21.2, C24.2, C25.2, C26.2, C28.1, C29.2, C31.2, C32.2, C33.2, C34.2, C35.2, C36.2, C37.2, C38.2, C39.2, C41.2, C42.2, C43.2, C44.1, C45.2, C46.2, C47.2, C48.2, C52.2, C53.2, DS1.1, DS1.3, DS1.5, DS1.6, DS1.10, DS1.11, DS1.12, DS1.13, DS1.14, DS1.15, DS1.17, DS1.19, DS1.20, J1.12, J1.30, J2.1, J2.3, J2.5, J2.7, J3.2, J4.4, J4.5, J4.9, J4.13, J4.14, J4.17, J4.18, J4.21, J5.1, J5.3, J5.5, J5.7, R9.2, R14.2, R41.2, R42.2, R43.2, R44.2, R45.1, R51.1, U1.2 (GND), U2.2 (GND), U2.4 (NC), U3.2 (GND), U3.4 (NC), U4.2 (GND), U4.4 (NC), U5.4 (AGND), U5.8 (AGND), U5.14 (AGND), U5.18 (AGND), U5.24 (AGND), U5.28 (AGND), U5.33 (DGND), U5.34 (ATEST[1]), U5.35 (ATEST[0]), U5.37 (AGND), U5.42 (DGND), U5.43 (DGND), U5.44 (DGND), U5.45 (VSYNC_in[2]), U5.46 (HSYNC_in[2]), U5.47 (VSYNC_in[1]), U5.48 (HSYNC_in[1]), U5.51 (DTEST[1]), U5.52 (DGND), U5.53 (DGND), U5.55 (DGND), U5.56 (DGND), U5.57 (DTEST[2]), U5.58 (DGND), U5.59 (DGND), U5.60 (DGND), U5.61 (CLKINV_in), U5.66 (FBC_in), U5.67 (SADDR), U5.70 (DGND), U5.73 (DTEST[3]), U5.74 (DTEST[4]), U5.75 (DGND), U5.82 (DGND), U5.89 (DGND), U5.96 (DGND), U5.103 (DGND), U5.110 (DGND), U5.117 (DGND), U5.128 (AGND), U6.7 (OEB), U6.EP (GND), U7.2 (AGND), U7.5 (DGND), U7.12 (FMT), U8.1 (GND)
unnamed: C13.1, U5.25 (B_in[0])
unnamed: C20.2, R1.1
unnamed: C22.2, U5.27 (G_in[0])
unnamed: C23.2, U5.31 (R_in[0])
unnamed: C24.1, U5.39 (XTAL_in), Y1.1
unnamed: C25.1, U5.40 (XTAL_out), Y1.2
unnamed: C42.1, C45.1, U7.1 (VREF)
unnamed: C47.1, R46.1, U7.14 (VINR)
unnamed: C48.1, R47.1, U7.13 (VINL)
unnamed: C49.1, R46.2
unnamed: C50.1, R47.2
unnamed: C51.1, R3.2, R51.2
unnamed: C51.2, U6.1 (XA)
unnamed: DS1.16, R49.1
unnamed: DS1.18, R50.1
unnamed: J5.2, R45.2, U5.54 (EXTCLK_in)
unnamed: JP1.1 (A), R48.2, U6.19 (CLK4)
unnamed: L1.1, U1.5 (SW)
unnamed: R1.2, U5.29 (SOG_in[0])
unnamed: R2.2, U5.126 (FIELD)
unnamed: R5.2, U5.123 (VSYNC_out)
unnamed: R6.2, U5.122 (HSYNC_out)
unnamed: R7.2, U5.121 (HS_out)
unnamed: R11.2, U5.114 (R[2])
unnamed: R12.2, U5.113 (R[3])
unnamed: R15.2, U5.112 (R[4])
unnamed: R16.2, U5.109 (R[5])
unnamed: R17.2, U5.108 (R[6])
unnamed: R18.2, U5.107 (R[7])
unnamed: R19.2, U5.106 (R[8])
unnamed: R20.2, U5.105 (R[9])
unnamed: R21.2, U5.100 (G[2])
unnamed: R22.2, U5.98 (G[4])
unnamed: R23.2, U5.95 (G[5])
unnamed: R24.2, U5.93 (G[7])
unnamed: R25.2, U5.91 (G[9])
unnamed: R26.2, U5.86 (B[2])
unnamed: R27.2, U5.84 (B[4])
unnamed: R28.2, U5.81 (B[5])
unnamed: R29.2, U5.79 (B[7])
unnamed: R30.2, U5.77 (B[9])
unnamed: R31.2, U5.99 (G[3])
unnamed: R32.2, U5.94 (G[6])
unnamed: R33.2, U5.92 (G[8])
unnamed: R34.2, U5.85 (B[3])
unnamed: R35.2, U5.80 (B[6])
unnamed: R36.2, U5.78 (B[8])
unnamed: R4.2, R38.1, U5.124 (INT_N)

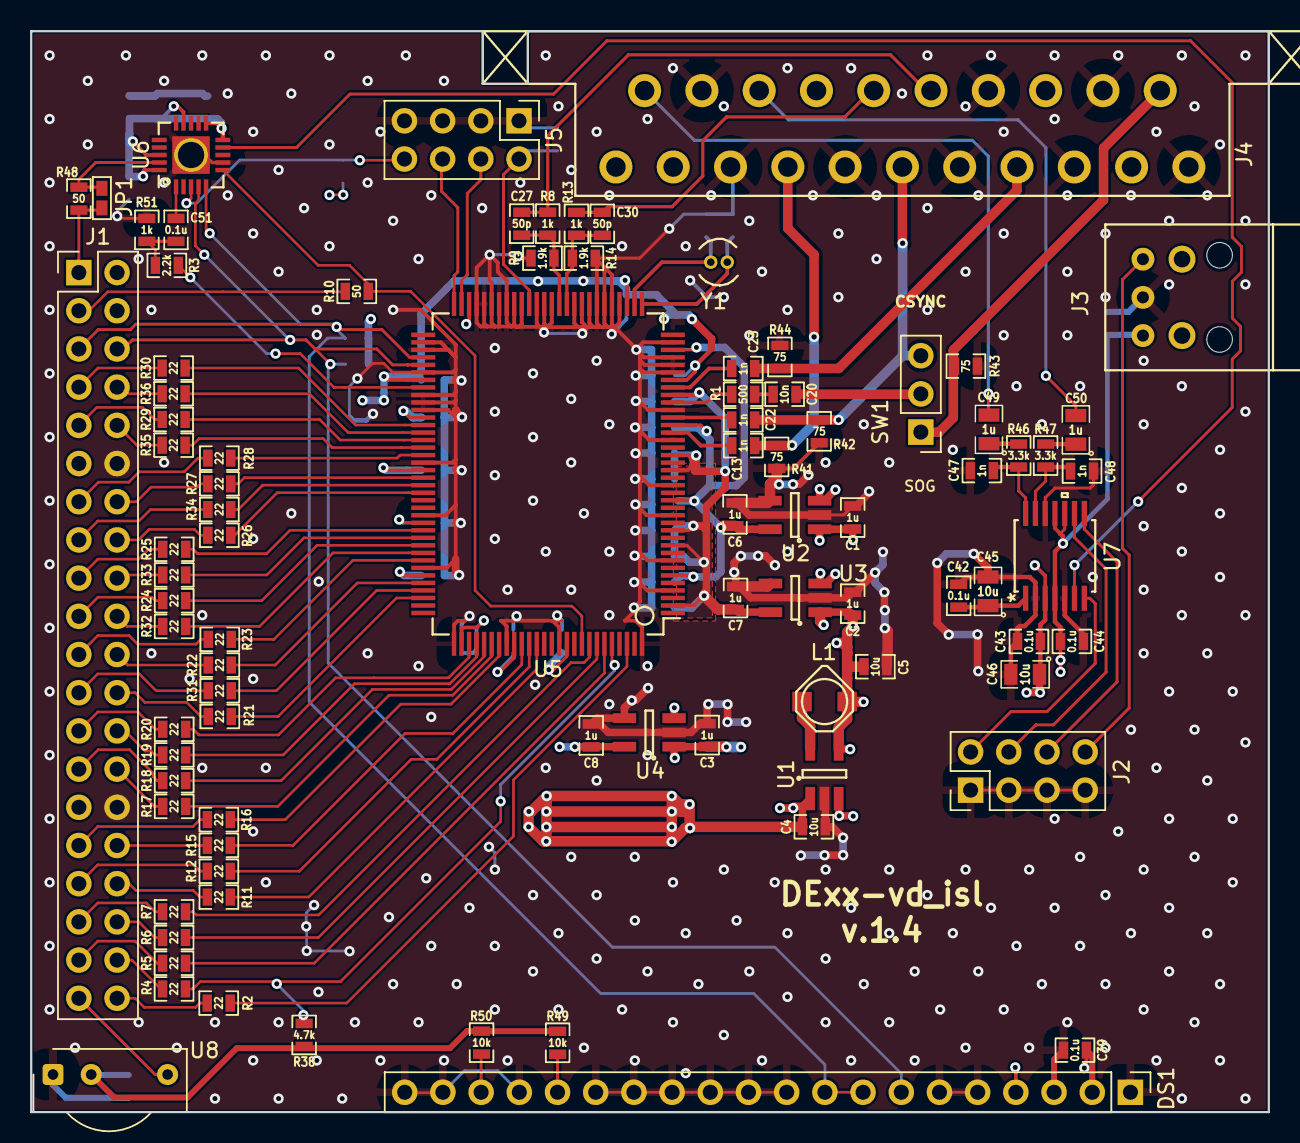
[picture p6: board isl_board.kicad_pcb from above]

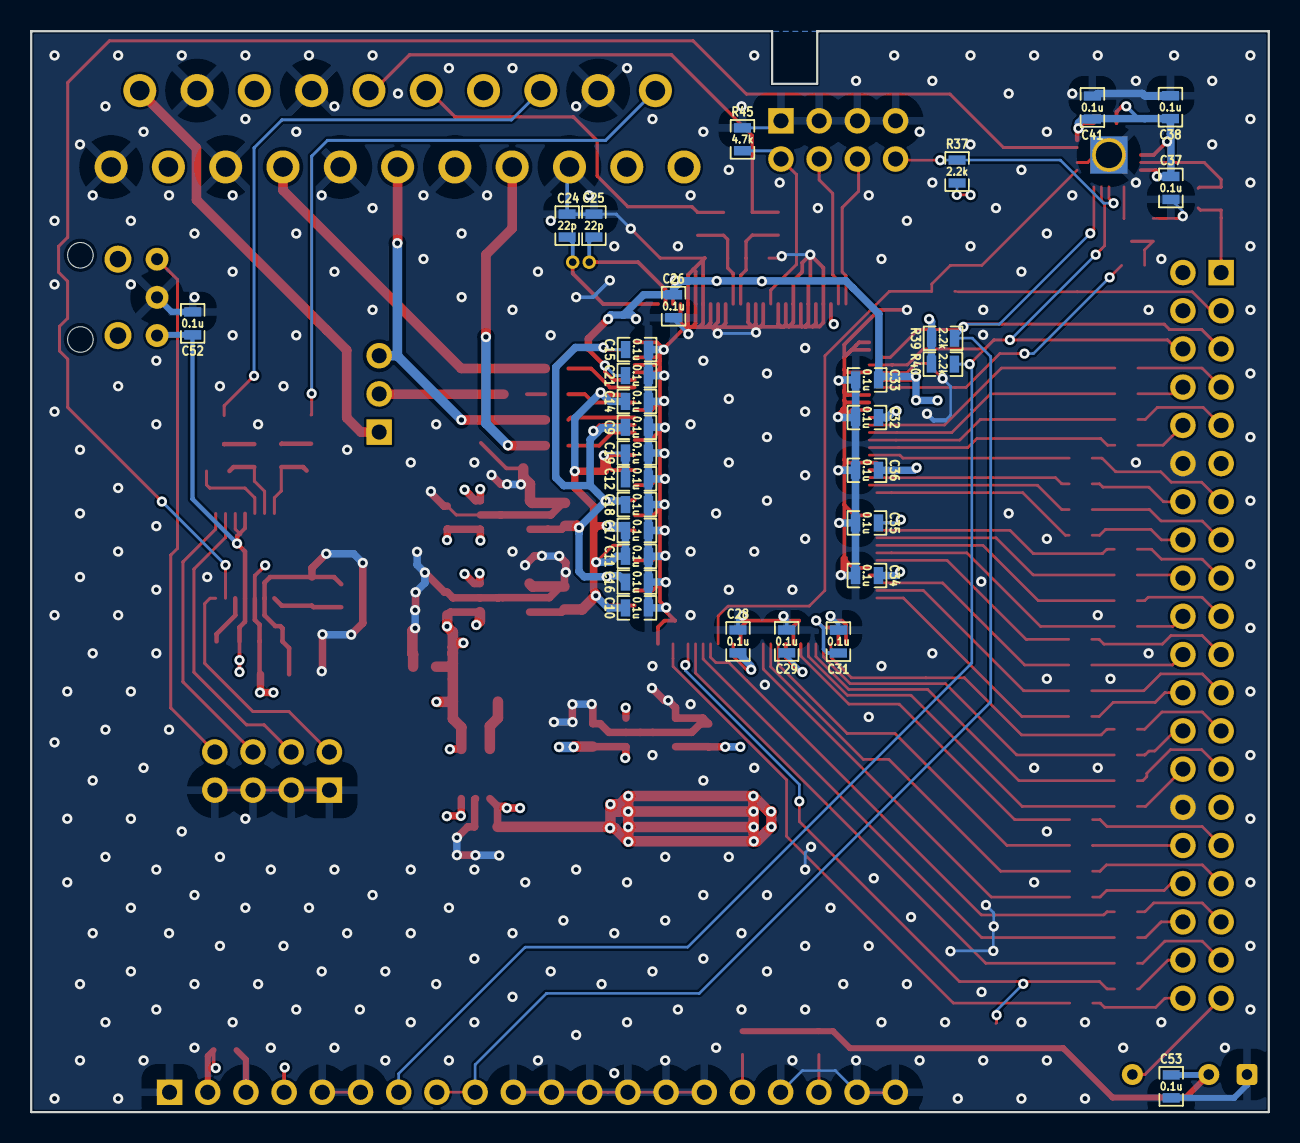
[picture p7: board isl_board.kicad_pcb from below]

Board: 4 copper layers, 82.3 x 71.9 mm, 121 parts (31 on the bottom side), 110 nets.

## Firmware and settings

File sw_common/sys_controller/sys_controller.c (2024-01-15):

//
// Copyright (C) 2019-2024  Markus Hiienkari <mhiienka@niksula.hut.fi>
//
// This file is part of Open Source Scan Converter project.
//
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

#include <stdio.h>
#include <unistd.h>
#include <string.h>
#include "i2c_opencores.h"
#include "altera_avalon_pio_regs.h"
#include "altera_avalon_timer.h"
#include <sys/alt_timestamp.h>
#include "system.h"
#include "bscanf.h"
#include "isl51002.h"
#ifdef INC_ADV7513
#include "adv7513.h"
#endif
#ifdef INC_SII1136
#include "sii1136.h"
#endif
#include "si5351.h"
#include "us2066.h"
#include "sc_config_regs.h"
#include "menu.h"
#include "mmc.h"
#include "file.h"
#include "controls.h"
#include "avconfig.h"
#include "av_controller.h"
#include "video_modes.h"
#include "flash.h"
#include "userdata.h"

#define FW_VER_MAJOR 0
#define FW_VER_MINOR 73

//fix PD and cec
#define ADV7513_MAIN_BASE 0x72
#define ADV7513_EDID_BASE 0x7e
#define ADV7513_PKTMEM_BASE 0x70
#define ADV7513_CEC_BASE 0x78

#define SII1136_BASE (0x72>>1)

#define ISL51002_BASE (0x98>>1)
#define SI5351_BASE (0xC0>>1)
#define US2066_BASE (0x7a>>1)

// Default settings
const settings_t ts_default = {
    .default_avinput = 0,
    .osd_enable = 1,
    .osd_status_timeout = 1,
};

isl51002_dev isl_dev = {.i2cm_base = I2C_OPENCORES_0_BASE,
                        .i2c_addr = ISL51002_BASE,
                        .xclk_out_en = 1,
                        .xtal_freq = 27000000LU};

si5351_dev si_dev = {.i2cm_base = I2C_OPENCORES_0_BASE,
                     .i2c_addr = SI5351_BASE,
                     .xtal_freq = 27000000LU};

#define SI_PCLK_PIN SI_CLK4

#ifdef INC_ADV7513
adv7513_dev advtx_dev = {.i2cm_base = I2C_OPENCORES_1_BASE,
                         .main_base = ADV7513_MAIN_BASE,
                         .edid_base = ADV7513_EDID_BASE,
                         .pktmem_base = ADV7513_PKTMEM_BASE,
                         .cec_base = ADV7513_CEC_BASE};
#endif

#ifdef INC_SII1136
sii1136_dev siitx_dev = {
#ifdef C5G
                         .i2cm_base = I2C_OPENCORES_2_BASE,
#else
                         .i2cm_base = I2C_OPENCORES_1_BASE,
#endif
                         .i2c_addr = SII1136_BASE};
#endif

us2066_dev chardisp_dev = {.i2cm_base = I2C_OPENCORES_0_BASE,
                           .i2c_addr = US2066_BASE};

flash_ctrl_dev flashctrl_dev = {.regs = (volatile gen_flash_if_regs*)INTEL_GENERIC_SERIAL_FLASH_INTERFACE_TOP_0_AVL_CSR_BASE,
#ifdef C5G
                                .flash_size = 0x2000000};
#else
                                .flash_size = 0x800000};
#endif

#ifdef DE2_115
alt_up_character_lcd_dev charlcd_dev = {.base = CHARACTER_LCD_0_BASE};
#endif

volatile sc_regs *sc = (volatile sc_regs*)SC_CONFIG_0_BASE;
volatile osd_regs *osd = (volatile osd_regs*)OSD_GENERATOR_0_BASE;

struct mmc *mmc_dev;
struct mmc * ocsdc_mmc_init(int base_addr, int clk_freq, unsigned int host_caps);

#ifdef DE10N
#define SDC_FREQ 50000000U
// IO constraints do not cover high speed mode
#define SDC_HOST_CAPS (MMC_MODE_4BIT)
#else
#define SDC_FREQ 100000000U
#define SDC_HOST_CAPS (MMC_MODE_HS|MMC_MODE_HS_52MHz|MMC_MODE_4BIT)
#endif

uint32_t sys_ctrl;
uint32_t sys_status;
uint8_t sys_powered_on;

uint8_t sl_def_iv_x, sl_def_iv_y;

uint8_t sd_det;

int enable_isl, enable_tp;
oper_mode_t oper_mode;

avinput_t avinput, target_avinput;

mode_data_t vmode_in, vmode_out;
vm_proc_config_t vm_conf;

settings_t cs, ts;

char row1[US2066_ROW_LEN+1], row2[US2066_ROW_LEN+1];
extern char menu_row1[US2066_ROW_LEN+1], menu_row2[US2066_ROW_LEN+1];

extern const char *avinput_str[];

FIL file;
char char_buff[256];

#include "src/shmask_arrays.c"

const shmask_data_arr* shmask_data_arr_list[] = {NULL, &shmask_agrille, &shmask_tv, &shmask_pvm, &shmask_pvm_2530, &shmask_xc_3315c, &shmask_c_1084, &shmask_jvc, &shmask_vga};
shmask_data_arr shmask_data_arr_custom;
shmask_data_arr *shmask_data_arr_ptr = &shmask_data_arr_custom;
int shmask_loaded_array = 0;
#define SHMASKS_SIZE  (sizeof(shmask_data_arr_list) / sizeof((shmask_data_arr_list)[0]))

#ifdef VIP
#include "src/scl_pp_coeffs.c"

const pp_coeff* scl_pp_coeff_list[][2][2] = {{{&pp_coeff_nearest, NULL}, {&pp_coeff_nearest, NULL}},
                                            {{&pp_coeff_lanczos3, NULL}, {&pp_coeff_lanczos3, NULL}},
                                            {{&pp_coeff_lanczos3_13, NULL}, {&pp_coeff_lanczos3_13, NULL}},
                                            {{&pp_coeff_lanczos3, &pp_coeff_lanczos3_13}, {&pp_coeff_lanczos3, &pp_coeff_lanczos3_13}},
                                            {{&pp_coeff_lanczos4, NULL}, {&pp_coeff_lanczos4, NULL}},
                                            {{&pp_coeff_gs_sharp, NULL}, {&pp_coeff_gs_sharp, NULL}}};
int scl_loaded_pp_coeff = -1;
#define PP_COEFF_SIZE  (sizeof(scl_pp_coeff_list) / sizeof((scl_pp_coeff_list)[0]))
#define PP_TAPS 4
#define PP_PHASES 64
#define SCL_ALG_COEFF_START 3

#define VIP_WDOG_VALUE 10

typedef struct {
    uint32_t ctrl;
    uint32_t status;
    uint32_t irq;
    uint32_t words;
    uint32_t h_active;
    uint32_t v_active_f0;
    uint32_t v_active_f1;
    uint32_t h_total;
    uint32_t v_total_f0;
    uint32_t v_total_f1;
} vip_cvi_ii_regs;

typedef struct {
    uint32_t ctrl;
    uint32_t status;
    uint32_t irq;
    uint32_t vmode_match;
    uint32_t banksel;
    uint32_t mode_ctrl;
    uint32_t h_active;
    uint32_t v_active;
    uint32_t v_active_f1;
    uint32_t h_frontporch;
    uint32_t h_synclen;
    uint32_t h_blank;
    uint32_t v_frontporch;
    uint32_t v_synclen;
    uint32_t v_blank;
    uint32_t v_frontporch_f0;
    uint32_t v_synclen_f0;
    uint32_t v_blank_f0;
    uint32_t active_start;
    uint32_t v_blank_start;
    uint32_t fid_r;
    uint32_t fid_f;
    uint32_t vid_std;
    uint32_t sof_sample;
    uint32_t sof_line;
    uint32_t vco_div;
    uint32_t anc_line;
    uint32_t anc_line_f0;
    uint32_t h_polarity;
    uint32_t v_polarity;
    uint32_t valid;
} vip_cvo_ii_regs;

typedef struct {
    uint32_t ctrl;
    uint32_t status;
    uint32_t irq;
    uint32_t width;
    uint32_t height;
    uint32_t edge_thold;
    uint32_t reserved[2];
    uint32_t h_coeff_wbank;
    uint32_t h_coeff_rbank;
    uint32_t v_coeff_wbank;
    uint32_t v_coeff_rbank;
    uint32_t h_phase;
    uint32_t v_phase;
    int32_t coeff_data[PP_TAPS];
} vip_scl_ii_regs;

typedef struct {
    uint32_t ctrl;
    uint32_t status;
    uint32_t rsv;
#ifndef VIP_DIL_B
    uint32_t unused[11];
    uint32_t motion_shift;
    uint32_t unused2;
    uint32_t mode;
#else
    uint32_t cadence_detected;
    uint32_t unused[8];
    uint32_t cadence_detect_enable;
    uint32_t unused2[12];
    uint32_t motion_shift;
    uint32_t unused3;
    uint32_t visualize_motion;
    uint32_t rsv2[2];
    uint32_t motion_scale;
#endif
} vip_dil_ii_regs;

typedef struct {
    uint32_t ctrl;
    uint32_t status;
    uint32_t irq;
    uint32_t config;
} vip_il_ii_regs;

typedef struct {
    uint32_t ctrl;
    uint32_t status;
    uint32_t irq;
    uint32_t frame_cnt;
    uint32_t drop_rpt_cnt;
    uint32_t unused[3];
    uint32_t misc;
    uint32_t locked;
    uint32_t input_rate;
    uint32_t output_rate;
} vip_vfb_ii_regs;

volatile vip_cvi_ii_regs *vip_cvi = (volatile vip_cvi_ii_regs*)ALT_VIP_CL_CVI_0_BASE;
volatile vip_dil_ii_regs *vip_dil = (volatile vip_dil_ii_regs*)ALT_VIP_CL_DIL_0_BASE;
volatile vip_vfb_ii_regs *vip_fb = (volatile vip_vfb_ii_regs*)ALT_VIP_CL_VFB_0_BASE;
volatile vip_scl_ii_regs *vip_scl_pp = (volatile vip_scl_ii_regs*)ALT_VIP_CL_SCL_0_BASE;
volatile vip_il_ii_regs *vip_il = (volatile vip_il_ii_regs*)ALT_VIP_CL_INTERLACER_0_BASE;
volatile vip_cvo_ii_regs *vip_cvo = (volatile vip_cvo_ii_regs*)ALT_VIP_CL_CVO_0_BASE;
#endif

si5351_ms_config_t si_audio_mclk_48k_conf = {3740, 628, 1125, 8832, 0, 1, 0, 0, 0};
si5351_ms_config_t si_audio_mclk_96k_conf = {3740, 628, 1125, 4160, 0, 2, 0, 0, 0};

void ui_disp_menu(uint8_t osd_mode)
{
    uint8_t menu_page;

    if ((osd_mode == 1) || (ts.osd_enable == 2)) {
        strncpy((char*)osd->osd_array.data[0][0], menu_row1, OSD_CHAR_COLS);
        strncpy((char*)osd->osd_array.data[1][0], menu_row2, OSD_CHAR_COLS);
        osd->osd_row_color.mask = 0;
        osd->osd_sec_enable[0].mask = 3;
        osd->osd_sec_enable[1].mask = 0;
    } else if (osd_mode == 2) {
        menu_page = get_current_menunavi()->mp;
        strncpy((char*)osd->osd_array.data[menu_page][1], menu_row2, OSD_CHAR_COLS);
        osd->osd_sec_enable[1].mask |= (1<<menu_page);
    }

    us2066_write(&chardisp_dev, (char*)&menu_row1, (char*)&menu_row2);

#ifdef DE2_115
    alt_up_character_lcd_init(&charlcd_dev);
    alt_up_character_lcd_string(&charlcd_dev, menu_row1);
    alt_up_character_lcd_set_cursor_pos(&charlcd_dev, 0, 1);
    alt_up_character_lcd_string(&charlcd_dev, menu_row2);
#endif
}

void ui_disp_status(uint8_t refresh_osd_timer) {
    if (!is_menu_active()) {
        if (refresh_osd_timer)
            osd->osd_config.status_refresh = 1;

        strncpy((char*)osd->osd_array.data[0][0], row1, OSD_CHAR_COLS);
        strncpy((char*)osd->osd_array.data[1][0], row2, OSD_CHAR_COLS);
        osd->osd_row_color.mask = 0;
        osd->osd_sec_enable[0].mask = 3;
        osd->osd_sec_enable[1].mask = 0;

        us2066_write(&chardisp_dev, (char*)&row1, (char*)&row2);

#ifdef DE2_115
        alt_up_character_lcd_init(&charlcd_dev);
        alt_up_character_lcd_string(&charlcd_dev, row1);
        alt_up_character_lcd_set_cursor_pos(&charlcd_dev, 0, 1);
        alt_up_character_lcd_string(&charlcd_dev, row2);
#endif
    }
}

void update_sc_config(mode_data_t *vm_in, mode_data_t *vm_out, vm_proc_config_t *vm_conf, avconfig_t *avconfig)
{
    int vip_enable, scl_target_pp_coeff, scl_ea, i, p, t, n;
    int v0,v1,v2,v3;
    char target_filename[16];
    uint32_t h_blank, v_blank, h_frontporch, v_frontporch;

    hv_config_reg hv_in_config = {.data=0x00000000};
    hv_config2_reg hv_in_config2 = {.data=0x00000000};
    hv_config3_reg hv_in_config3 = {.data=0x00000000};
    hv_config_reg hv_out_config = {.data=0x00000000};
    hv_config2_reg hv_out_config2 = {.data=0x00000000};
    hv_config3_reg hv_out_config3 = {.data=0x00000000};
    xy_config_reg xy_out_config = {.data=0x00000000};
    xy_config2_reg xy_out_config2 = {.data=0x00000000};
    xy_config3_reg xy_out_config3 = {.data=0x00000000};
    misc_config_reg misc_config = {.data=0x00000000};
    sl_config_reg sl_config = {.data=0x00000000};
    sl_config2_reg sl_config2 = {.data=0x00000000};
    sl_config3_reg sl_config3 = {.data=0x00000000};

#ifdef VIP
    vip_enable = !enable_tp && (avconfig->oper_mode == 1);
#else
    vip_enable = 0;
#endif

    if (avconfig->shmask_mode && (avconfig->shmask_mode != shmask_loaded_array)) {
        if (avconfig->shmask_mode >= SHMASKS_SIZE) { // Custom
            sniprintf(target_filename, sizeof(target_filename), "shmask%d.txt", (avconfig->shmask_mode + 1 - SHMASKS_SIZE) );
            if (!file_open(&file, target_filename)) {
                i = 0;
                while (file_get_string(&file, char_buff, sizeof(char_buff))) {
                    if (char_buff[0] == '#')
                        continue;
                    if (!i && (bscanf(char_buff, "%d,%d", &v0, &v1) == 2)) {
                        shmask_data_arr_custom.iv_x = v0-1;
                        shmask_data_arr_custom.iv_y = v1-1;
                        i = 1;
                    } else if (i && (v1 > 0)) {
                        p = shmask_data_arr_custom.iv_y+1-v1;
                        if (bscanf(char_buff, "%hx,%hx,%hx,%hx,%hx,%hx,%hx,%hx,%hx,%hx,%hx,%hx,%hx,%hx,%hx,%hx", &shmask_data_arr_custom.v[p][0],
                                                                                                                 &shmask_data_arr_custom.v[p][1],
                                                                                                                 &shmask_data_arr_custom.v[p][2],
                                                                                                                 &shmask_data_arr_custom.v[p][3],
                                                                                                                 &shmask_data_arr_custom.v[p][4],
                                                                                                                 &shmask_data_arr_custom.v[p][5],
                                                                                                                 &shmask_data_arr_custom.v[p][6],
                                                                                                                 &shmask_data_arr_custom.v[p][7],
                                                                                                                 &shmask_data_arr_custom.v[p][8],
                                                                                                                 &shmask_data_arr_custom.v[p][9],
                                                                                                                 &shmask_data_arr_custom.v[p][10],
                                                                                                                 &shmask_data_arr_custom.v[p][11],
                                                                                                                 &shmask_data_arr_custom.v[p][12],
                                                                                                                 &shmask_data_arr_custom.v[p][13],
                                                                                                                 &shmask_data_arr_custom.v[p][14],
                                                                                                                 &shmask_data_arr_custom.v[p][15]) == v0)
                            v1--;
                    }
                }
                file_close(&file);
            }

            shmask_data_arr_ptr = &shmask_data_arr_custom;
        } else {
            shmask_data_arr_ptr = (shmask_data_arr*)shmask_data_arr_list[avconfig->shmask_mode];
        }

        for (p=0; p<=shmask_data_arr_ptr->iv_y; p++) {
            for (t=0; t<=shmask_data_arr_ptr->iv_x; t++)
                sc->shmask_data_array.data[p][t] = shmask_data_arr_ptr->v[p][t];
        }

        shmask_loaded_array = avconfig->shmask_mode;
    }

    // Set input params
    hv_in_config.h_total = vm_in->timings.h_total;
    hv_in_config.h_active = vm_in->timings.h_active;
    hv_in_config.h_synclen = vm_in->timings.h_synclen;
    hv_in_config2.h_backporch = vm_in->timings.h_backporch;
    hv_in_config3.v_active = vm_in->timings.v_active;
    hv_in_config3.v_synclen = vm_in->timings.v_synclen;
    hv_in_config2.v_backporch = vm_in->timings.v_backporch;
    hv_in_config2.interlaced = vm_in->timings.interlaced;
    hv_in_config2.h_skip = vm_conf->h_skip;
    hv_in_config2.h_sample_sel = vm_conf->h_sample_sel;

    // Set output params
    hv_out_config.h_total = vm_out->timings.h_total;
    hv_out_config.h_active = vm_out->timings.h_active;
    hv_out_config.h_synclen = vm_out->timings.h_synclen;
    hv_out_config2.h_backporch = vm_out->timings.h_backporch;
    hv_out_config2.v_total = vm_out->timings.v_total;
    hv_out_config3.v_active = vm_out->timings.v_active;
    hv_out_config3.v_synclen = vm_out->timings.v_synclen;
    hv_out_config2.v_backporch = vm_out->timings.v_backporch;
    hv_out_config2.interlaced = vm_out->timings.interlaced;
    hv_out_config3.v_startline = vm_conf->framesync_line;

    xy_out_config.x_size = vm_conf->x_size;
    xy_out_config.y_size = vm_conf->y_size;
    xy_out_config2.y_offset = vm_conf->y_offset;
    xy_out_config2.x_offset = vm_conf->x_offset;
    xy_out_config3.x_start_lb = vm_conf->x_start_lb;
    xy_out_config3.y_start_lb = vm_conf->y_start_lb;
    xy_out_config.x_rpt = vm_conf->x_rpt;
    xy_out_config.y_rpt = vm_conf->y_rpt;

    misc_config.mask_br = avconfig->mask_br;
    misc_config.mask_color = avconfig->mask_color;
    misc_config.reverse_lpf = avconfig->reverse_lpf;
    misc_config.lm_deint_mode = avconfig->lm_deint_mode;
    misc_config.nir_even_offset = avconfig->nir_even_offset;
    misc_config.ypbpr_cs = (avconfig->ypbpr_cs == 0) ? ((vm_in->type & VIDEO_HDTV) ? 1 : 0) : avconfig->ypbpr_cs-1;
    misc_config.vip_enable = vip_enable;
    misc_config.bfi_enable = avconfig->bfi_enable & ((uint32_t)vm_out->timings.v_hz_x100*5 >= (uint32_t)vm_in->timings.v_hz_x100*9);
    misc_config.bfi_str = avconfig->bfi_str;
    misc_config.shmask_enable = (avconfig->shmask_mode != 0);
    misc_config.shmask_iv_x = shmask_data_arr_ptr->iv_x;
    misc_config.shmask_iv_y = shmask_data_arr_ptr->iv_y;

    // set default/custom scanline interval
    sl_def_iv_y = (vm_conf->y_rpt > 0) ? vm_conf->y_rpt : 1;
    sl_def_iv_x = (vm_conf->x_rpt > 0) ? vm_conf->x_rpt : sl_def_iv_y;
    sl_config3.sl_iv_x = ((avconfig->sl_type == 3) && (avconfig->sl_cust_iv_x)) ? avconfig->sl_cust_iv_x : sl_def_iv_x;
    sl_config3.sl_iv_y = ((avconfig->sl_type == 3) && (avconfig->sl_cust_iv_y)) ? avconfig->sl_cust_iv_y : sl_def_iv_y;

    // construct custom/default scanline overlay
    for (i=0; i<6; i++) {
        if (avconfig->sl_type == 3) {
            sl_config.sl_l_str_arr |= ((avconfig->sl_cust_l_str[i]-1)&0xf)<<(4*i);
            sl_config.sl_l_overlay |= (avconfig->sl_cust_l_str[i]!=0)<<i;
        } else {
            sl_config.sl_l_str_arr |= avconfig->sl_str<<(4*i);

            if ((i==5) && ((avconfig->sl_type == 0) || (avconfig->sl_type == 2))) {
                sl_config.sl_l_overlay = (1<<((sl_config3.sl_iv_y+1)/2))-1;
                if (avconfig->sl_id)
                    sl_config.sl_l_overlay <<= (sl_config3.sl_iv_y+2)/2;
            }
        }
    }
    for (i=0; i<10; i++) {
        if (avconfig->sl_type == 3) {
            if (i<8)
                sl_config2.sl_c_str_arr_l |= ((avconfig->sl_cust_c_str[i]-1)&0xf)<<(4*i);
            else
                sl_config3.sl_c_str_arr_h |= ((avconfig->sl_cust_c_str[i]-1)&0xf)<<(4*(i-8));
            sl_config3.sl_c_overlay |= (avconfig->sl_cust_c_str[i]!=0)<<i;
        } else {
            if (i<8)
                sl_config2.sl_c_str_arr_l |= avconfig->sl_str<<(4*i);
            else
                sl_config3.sl_c_str_arr_h |= avconfig->sl_str<<(4*(i-8));

            if ((i==9) && ((avconfig->sl_type == 1) || (avconfig->sl_type == 2)))
                sl_config3.sl_c_overlay = (1<<((sl_config3.sl_iv_x+1)/2))-1;
        }
    }
    sl_config.sl_method = avconfig->sl_method;
    sl_config.sl_altern = avconfig->sl_altern;
    sl_config3.sl_hybr_str = avconfig->sl_hybr_str;

    // disable scanlines if configured so
    if (((avconfig->sl_mode == 1) && (!vm_conf->y_rpt)) || (avconfig->sl_mode == 0)) {
        sl_config.sl_l_overlay = 0;
        sl_config3.sl_c_overlay = 0;
    }

    h_blank = vm_out->timings.h_total-vm_conf->x_size;
    v_blank = (vm_out->timings.v_total>>vm_out->timings.interlaced)-vm_conf->y_size;
    h_frontporch = h_blank-vm_conf->x_offset-vm_out->timings.h_backporch-vm_out->timings.h_synclen;
    v_frontporch = v_blank-vm_conf->y_offset-vm_out->timings.v_backporch-vm_out->timings.v_synclen;

    // VIP frame reader swaps buffers at the end of read frame while writer apparently does it just before frame to be written (?)
    // SOF needs to be offset accordingly to minimize FB latency
    hv_in_config3.v_startline = vm_in->timings.v_synclen+vm_in->timings.v_backporch+20+((v_frontporch*100*vm_in->timings.v_total)/(100*vm_out->timings.v_total));

    sc->hv_in_config = hv_in_config;
    sc->hv_in_config2 = hv_in_config2;
    sc->hv_in_config3 = hv_in_config3;
    sc->hv_out_config = hv_out_config;
    sc->hv_out_config2 = hv_out_config2;
    sc->hv_out_config3 = hv_out_config3;
    sc->xy_out_config = xy_out_config;
    sc->xy_out_config2 = xy_out_config2;
    sc->xy_out_config3 = xy_out_config3;
    sc->misc_config = misc_config;
    sc->sl_config = sl_config;
    sc->sl_config2 = sl_config2;
    sc->sl_config3 = sl_config3;

#ifdef VIP
    vip_cvi->ctrl = vip_enable;
    vip_dil->ctrl = vip_enable;
    vip_il->ctrl = vip_enable;

    if (avconfig->scl_alg == 0)
        scl_target_pp_coeff = ((vm_in->group >= GROUP_240P) && (vm_in->group <= GROUP_288P)) ? 0 : 2; // Nearest or Lanchos3_sharp
    else if (avconfig->scl_alg < SCL_ALG_COEFF_START)
        scl_target_pp_coeff = 0; // Nearest for integer scale
    else
        scl_target_pp_coeff = avconfig->scl_alg-SCL_ALG_COEFF_START;
    scl_ea = (scl_target_pp_coeff >= PP_COEFF_SIZE) ? 0 : !!scl_pp_coeff_list[scl_target_pp_coeff][0][1];

    vip_scl_pp->ctrl = vip_enable ? (scl_ea<<1)|1 : 0;
    vip_fb->ctrl = vip_enable;
    vip_cvo->ctrl = vip_enable ? (1 | (1<<3)) : 0;

    if (!vip_enable) {
        scl_loaded_pp_coeff = -1;
        return;
    }

#ifndef VIP_DIL_B
    if (avconfig->scl_dil_alg == 0) {
        vip_dil->mode = (1<<1);
    } else if (avconfig->scl_dil_alg == 1) {
        vip_dil->mode = (1<<2);
    } else if (avconfig->scl_dil_alg == 3) {
        vip_dil->mode = (1<<0);
    } else {
        vip_dil->mode = 0;
    }
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
int main()
{
    int ret;

    // Start system clock
    alt_timestamp_start();

    while (1) {
        ret = init_hw();
        if (ret != 0) {
            sniprintf(row2, US2066_ROW_LEN+1, "Error code: %d", ret);
            printf("%s\n%s\n", row1, row2);
            us2066_display_on(&chardisp_dev);
            ui_disp_status(1);
            while (1) {}
        }

        printf("### DExx-vd INIT OK ###\n\n");

        sys_powered_on = 1;

        // Powerup
        sys_ctrl |= SCTRL_POWER_ON;
        sys_ctrl &= ~SCTRL_EMIF_POWERDN_REQ;
        IOWR_ALTERA_AVALON_PIO_DATA(PIO_0_BASE, sys_ctrl);

        // Invalidate input
        avinput = (avinput_t)-1;

        us2066_display_on(&chardisp_dev);

#ifdef INC_SII1136
        sii1136_enable_power(&siitx_dev, 1);
#endif

        mainloop();
    }
}

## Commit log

2018-12-10 add files for original board revision
    [isl_board-B.Cu.gbr, isl_board-B.Mask.gbr, isl_board-B.Paste.gbr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]
2020-01-26 update PCB to v1.1
    [isl_board-B.Cu.gbr, isl_board-B.Mask.gbr, isl_board-B.Paste.gbr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]
2020-02-06 add PCB v1.1 gerbers
    [isl_board-B.Cu.gbl, isl_board-B.Mask.gbs, isl_board-B.Paste.gbp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]
2020-02-06 update PCB to v1.2
    [isl_board-B.Cu.gbl, isl_board-B_Cu.gbl, isl_board-B_Mask.gbs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]
2020-03-09 update BOM
    [isl_board.ods]
2020-05-19 add support for DE2-115 dev board
2020-08-11 update PCB to v1.3
    [isl_board-B_Cu.gbl, isl_board-B_Mask.gbs, isl_board-B_Paste.gbp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]
2020-08-30 update code and assignments for v1.3 PCB
2021-02-06 project port to C5G development board
2021-04-17 scaler mode fixes and VIP performance bump
    [sys_controller.c]
2021-04-19 fix framelock config selection for 2x mode
    [sys_controller.c]
2021-04-25 simplify framelock configs and add 100/120Hz modes
2021-05-05 update scaling filter selection
    * enable runtime configuration of PP coeffs
    * enable edge-adaptive mode for SCL
    * add a few extra preset filters
2022-04-21 reduce I2C drive strength to minimize interference
2022-05-01 update PCB to v1.4
    [isl_board-B_Cu.gbl, isl_board-B_Mask.gbs, isl_board-B_Paste.gbp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]
2022-07-20 improve adv7513 video interface timing
    Based on testing with multiple boards, ADV7513 setup and hold times given
    in its Hardware User Guide align with Clock Delay register (0xBA) value
    3 (no delay). This is in conflict with a support forum thread [1] but
    aligns with another thread [2] which implies that listed setup/hold values
    can be adjusted by +/-1.2ns. The change should fix artifacts in 2560x1440_60
    output mode.
    [1] https://ez.analog.com/video/f/q-a/10535/adv7513-input-video-data-timings
    [2] https://ez.analog.com/video/f/q-a/11229/adv7513-power-rail-consumption-and-bus-timings/39377
2022-07-20 initial implementation of SD save/load profile
    On DE10-Nano MMC block writes are offset by one word maybe due to IO timing
    issue. Bitstream / image files should be generated only after the problem
    has been fixed.
    [sys_controller.c]
2022-07-28 workaround for MMC block write issue
    [sys_controller.c]
2022-07-29 firmware release 0.59
    * MMC bwrite issue fixed properly
    * PLLs merged on DE10-Nano version
    * QSYS reset signal routing simplified
    * SD image compressed to reduce repo/download size
    [sys_controller.c]
2022-09-10 add dexx_video_adapter pcb design
    [dexx_video_adapter-B_Cu.gbr, dexx_video_adapter-B_Mask.gbr, dexx_video_adapter-B_Paste.gbr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]

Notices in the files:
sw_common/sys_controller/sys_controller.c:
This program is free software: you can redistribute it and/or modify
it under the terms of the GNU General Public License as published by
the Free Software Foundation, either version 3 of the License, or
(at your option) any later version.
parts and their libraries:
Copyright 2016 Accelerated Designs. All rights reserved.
